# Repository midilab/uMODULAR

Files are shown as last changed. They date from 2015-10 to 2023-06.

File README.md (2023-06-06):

# uMODULAR

A collection of **hardware schematics**, **PCBs**, and **libraries** for **real-time embedded applications** in the field of music and video.
  
Image of umodular-v2 series
  
**Hardware:** Modules effortlessly combine to enhance and extend the capabilities of your device.  
**Firmware:** All the challenging and intricate aspects of real-time and concurrency in music or video applications are encapsulated within a safe and intuitive API via libraries.  

The framework provides multi-architecture support, allowing for seamless compilation across various microcontrollers without the need for manual adjustments or modifications. This ensures a streamlined development process and simplifies the programming and debugging tasks associated with real-time and concurrent operations.  

## Hardware

The physical modules are released under the CC-BY-SA 4.0 license and are available in Kicad format, providing electronic schematics and PCB designs for creating your own audio/video/sensorial device controller or signal processing box.  

## Protocol interfaces

The uMODULAR framework is meticulously designed to ensure seamless interoperability with a wide range of audio and video devices available on the market. Its compatibility extends to various protocols and standards, allowing integration with different devices.  
  
Avaliable Interfaces:  
  
**MIDI**  
OSC: **On roadmap**  
CV/GATE: **On roadmap**  
DMX: **On roadmap**  

## Libraries

The firmware libraries are built for the Arduino platform, with support for PlatformIO, and are compatible with various microcontroller architectures and boards, including classic AVRs and modern ARMs.  
  
**AVRs:** ATmega168, ATmega328, ATmega16u4, ATmega32u4 and ATmega2560.  
**ARMs:** ESP32, SAMD21 and All Teensy ARM microcontrollers.  
  
**Boards:** All AVR Arduino boards, All Teensy AVRs and ARMs, ESP32 based boards and Seedstudio XIAO M0.  
  
#### uCtrl

[uCtrl](https://github.com/midilab/uCtrl) is a comprehensive codebase library for the uMODULAR hardware project. It offers a driver layer for all uMODULAR modules and a user interface layer that simplifies the creation, extension, and sharing of advanced Arduino/PlatformIO applications.  
  
With uCtrl, you can achieve realtime-like functionality within the Arduino/PlatformIO ecosystem by leveraging hardware timer interruptions for precise task management. The library provides a resource-safe access through its API, ensuring efficient and reliable operation.  
  
Choose uCtrl for developing robust, portable, and high-performance musical instruments, sequencers, audio/video controllers, and other related machines on the Arduino/PlatformIO platform.  
  
#### uClock

[uClock](https://github.com/midilab/uClock) is a BPM-based Clock Generator Library provides a way to implement BPM clock tick calls using hardware interruption, ensuring the tightest and most accurate clock signal possible.  

## Applications

Real world applications using the uMODULAR framework:  

#### Aciduino V2

The project features a versatile step sequencer clone of Roland’s TB303/TR808, offering up to 16 tracks. It includes a comprehensive automation grid system for step, pattern, and mute control. The sequencer functions as a MIDI controller and incorporates an OLED display for visual feedback. Furthermore, the design is modular and allows for easy expansion with additional potentiometers, buttons, MIDI, or CV/Gate interfaces.  
  
You can download the app at [aciduino v2 repository](https://github.com/midilab/aciduino/tree/master/v2)  

## Oficial Website

You can find more informations about uMODULAR at http://midilab.co/umodular.

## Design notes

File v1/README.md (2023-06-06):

# V1 release

### Shileds

The initial shield released is compatible with the Arduino Mega, Micro and Mini series boards. However, the project has plans to expand support for other board models in the future.

**\+ Arduino Micro and Mini 5v Compatible** **\+ Arduino Mega Compatible**  
mega_and_mini_shields

### IO Interfaces

The project provides various input and output interfaces, allowing users to interact with the external world effectively.

**\+ FADER8**: 8 x 60mm faders module – designed for Bourns PTA6043-2015DPB103 part. fader8

**\+ POT8**: 8 x potentiometers module – designed for Bourns PTV09A-4015F-B103 part. But it fits for almost all 10KB throughhole potentiometer models.  
pot8

**\+ PUSH8**: 8 x button/led module push8

### Midi Interface

**\+ MIDI4**: Common MIDI interface with support for 2 MIDI Inputs and 2 MIDI Outputs. midi4

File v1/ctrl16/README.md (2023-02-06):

# ctrl16 module

ctrl16 is a 10cmx12.5cm PCB module for uMODULAR platform ready for 16 potentiometers plus 8 buttons/leds to make your device ready for controlling audio or video hardware/software stuffs.

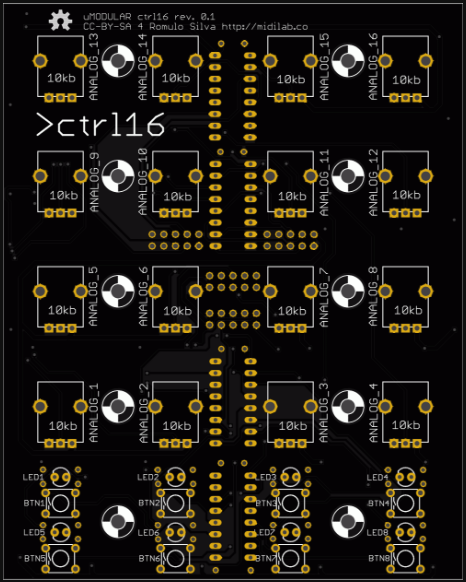
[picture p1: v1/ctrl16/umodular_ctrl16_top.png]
Image of uMODULAR ctrl16 pcb top view

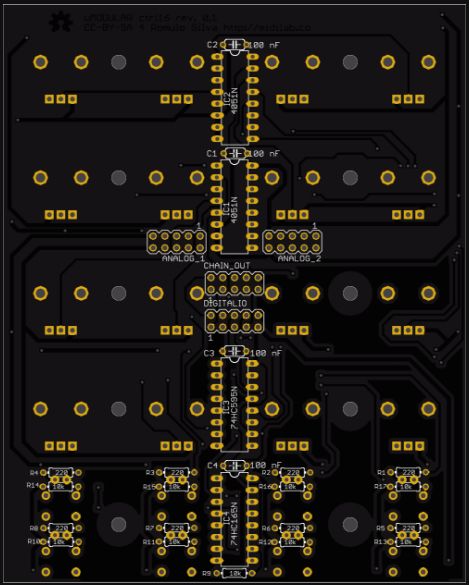
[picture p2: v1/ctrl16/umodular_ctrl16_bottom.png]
Image of uMODULAR ctrl16 pcb bottom view


## BOM list

### Buttons
**8x** Tactile Switches 6.0X4.3MM 160G <br />

### Leds
**8x** Through Hole Diffused T-1 (3 mm) <br />

### Potentiometers
**16x** 10K LINEAR 20%(Bourns PTV09A-4015F-B103) <br />

### ICs
**2x** CD4051BE <br />
**1x** 74HC595N <br />
**1x** 74HC165N <br />
**4x** Socket 16P DUAL WIPE <br />

### Ceramic Disc Capacitors 
**4x** 50V 100nf(.1uF) <br />

### Metal Film Resistors 1/4W Resistors
**8x** 220 <br />
**9x** 10k <br />

### Headers & Wire Housings 
**4x** 05+05 DIL VERTICAL PIN HEADER <br />

### Cable connection for uMODULAR base shield
**pick your size** Ribbon Cable 10 Conductors 28 AWG .050 <br />
**8x** Female Ribbon Cable Header 10 Position, 2 rows, 2.54 mm pitch <br />

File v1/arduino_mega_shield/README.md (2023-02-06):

# uMODULAR Arduino Mega Shield

This is a Arduino Mega Shield to support all uMODULAR modules.

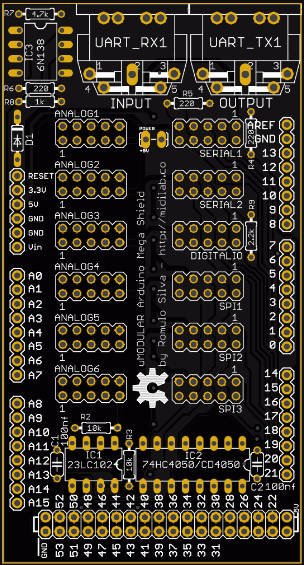
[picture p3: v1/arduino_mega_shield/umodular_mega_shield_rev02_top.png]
Image of uMODULAR Arduino Mega Shield pcb top view

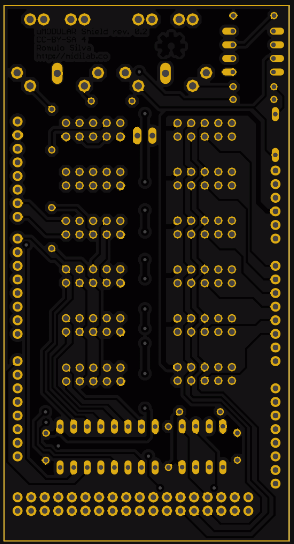
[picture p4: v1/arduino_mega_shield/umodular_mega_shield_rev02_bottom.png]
Image of uMODULAR Arduino Mega Shield pcb bottom view


## BOM list

### ICs
**1x** 23LC1024-I/P <br />
**1x** 74HC4050 <br />
**1x** 6N138 <br />
**1x** Socket 16P DUAL WIPE <br />
**2x** Socket 08P DUAL WIPE <br />

### Ceramic Disc Capacitors
**2x** 50V 100nf(.1uF) <br />

### Metal Film Resistors 1/4W Resistors
**3x** 220 <br />
**1x** 1k <br />
**1x** 2.2k <br />
**1x** 4.7k <br />
**2x** 10k <br />

### Diode
**1x** 1N4148TR <br />

### MIDI Connector
**2x** Circular DIN Connectors 5P R/A PCB SHIELDED 5mm CIRC DIN RECPT <br />

### Headers & Wire Housings
**12x** 05+05 DIL VERTICAL PIN HEADER <br />
**1x** 18+18 DIL VERTICAL PIN HEADER <br />
**5x** 08 SIL VERTICAL PIN HEADER TIN <br />
**1x** 06 SIL VERTICAL PIN HEADER TIN <br />
**1x** 02 SIL VERTICAL PIN HEADER TIN <br />

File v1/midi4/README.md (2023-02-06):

# midi4 module

midi4 is a 10cmx2.5cm PCB module for uMODULAR platform that supports 2 MIDI Ins and 2 MIDI Outs ports.

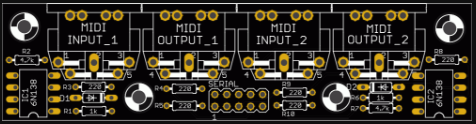
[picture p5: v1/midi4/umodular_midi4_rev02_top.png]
Image of uMODULAR midi4 pcb top view

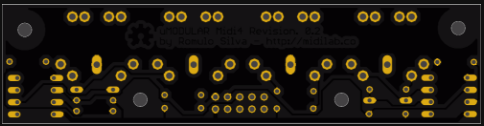
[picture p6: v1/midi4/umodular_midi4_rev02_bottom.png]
Image of uMODULAR midi4 pcb bottom view


## BOM list

### MIDI Connector
**4x** Circular DIN Connectors 5P R/A PCB SHIELDED 5mm CIRC DIN RECPT <br />

### IC
**2x** 6N138 <br />
**2x** Socket 8P DUAL WIPE <br />

### Metal Film Resistors 1/4W Resistors
**2x** 4.7k <br />
**6x** 220 <br />
**2x** 1k <br />

### Diode
**2x** 1N4148 <br />

### Headers & Wire Housings
**1x** 05+05 DIL VERTICAL PIN HEADER <br />

### Cable connection for uMODULAR base shield
**pick your size** Ribbon Cable 10 Conductors 28 AWG .050 <br />
**2x** Female Ribbon Cable Header 10 Position, 2 rows, 2.54 mm pitch <br />

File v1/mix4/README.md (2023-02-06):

# mix4 module

mix4 is a 10cmx12.5cm PCB module for uMODULAR platform ready for 4 faders and 4 potentiometers plus 8 buttons/leds to make your device ready for controlling audio or video hardware/software stuffs.

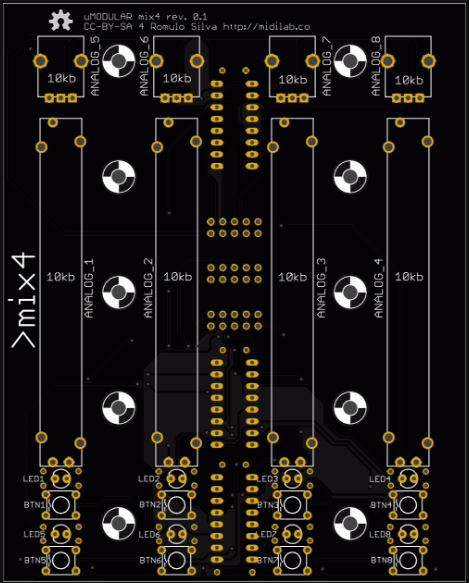
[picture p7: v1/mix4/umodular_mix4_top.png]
Image of uMODULAR mix4 pcb top view

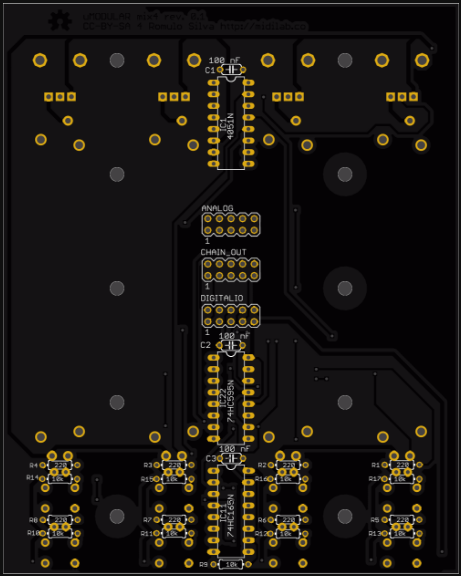
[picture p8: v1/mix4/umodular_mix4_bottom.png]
Image of uMODULAR mix4 pcb bottom view


## BOM list

### Buttons
**8x** Tactile Switches 6.0X4.3MM 160G <br />

### Leds
**8x** Through Hole Diffused T-1 (3 mm) <br />

### Potentiometers
**4x** 10K LINEAR 20% (Bourns PTV09A-4015F-B103) <br />
**4x** Slide 15MM SHAFT NO DET 60MM STRK SNG LIN (Bourns PTA6043-2015DPB103) <br />

### ICs
**1x** CD4051BE <br />
**1x** 74HC595N <br />
**1x** 74HC165N <br />
**3x** Socket 16P DUAL WIPE <br />

### Ceramic Disc Capacitors
**3x** 50V 100nf(.1uF) <br />

### Metal Film Resistors 1/4W Resistors
**8x** 220 <br />
**9x** 10k <br />

### Headers & Wire Housings
**3x** 05+05 DIL VERTICAL PIN HEADER <br />

### Cable connection with uMODULAR base
**pick your size** Ribbon Cable 10 Conductors 28 AWG .050
**6x** Female Ribbon Cable Header 10 Position, 2 rows, 2.54 mm pitch

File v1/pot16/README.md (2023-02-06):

# pot16 module

pot16 is a 10cmx10cm PCB module for uMODULAR platform ready for 16 potentiometers to make your device ready for controlling audio or video hardware/software stuffs.

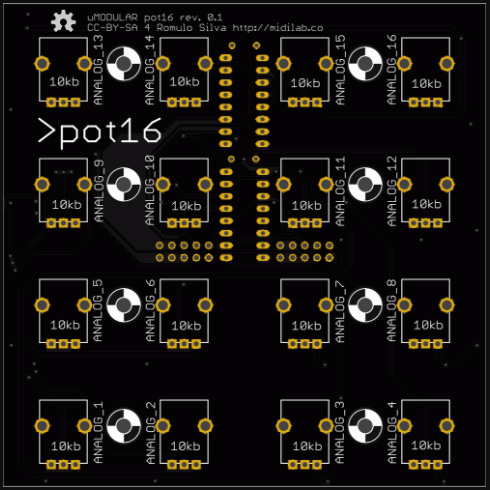
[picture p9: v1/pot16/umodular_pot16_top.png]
Image of uMODULAR pot16 pcb top view

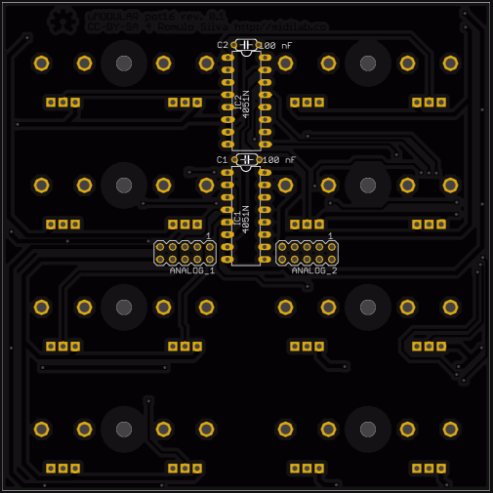
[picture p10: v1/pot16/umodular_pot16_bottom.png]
Image of uMODULAR pot16 pcb bottom view


## BOM list

### Potentiometers
**16x** 10K LINEAR 20%(Bourns PTV09A-4015F-B103) <br />

### ICs
**2x** CD4051BE <br />
**2x** Socket 16P DUAL WIPE <br />

### Ceramic Disc Capacitors
**2x** 50V 100nf(.1uF) <br />

### Headers & Wire Housings
**2x** 05+05 DIL VERTICAL PIN HEADER <br />

### Cable connection with uMODULAR base
**pick your size** Ribbon Cable 10 Conductors 28 AWG .050 <br />
**4x** Female Ribbon Cable Header 10 Position, 2 rows, 2.54 mm pitch <br />

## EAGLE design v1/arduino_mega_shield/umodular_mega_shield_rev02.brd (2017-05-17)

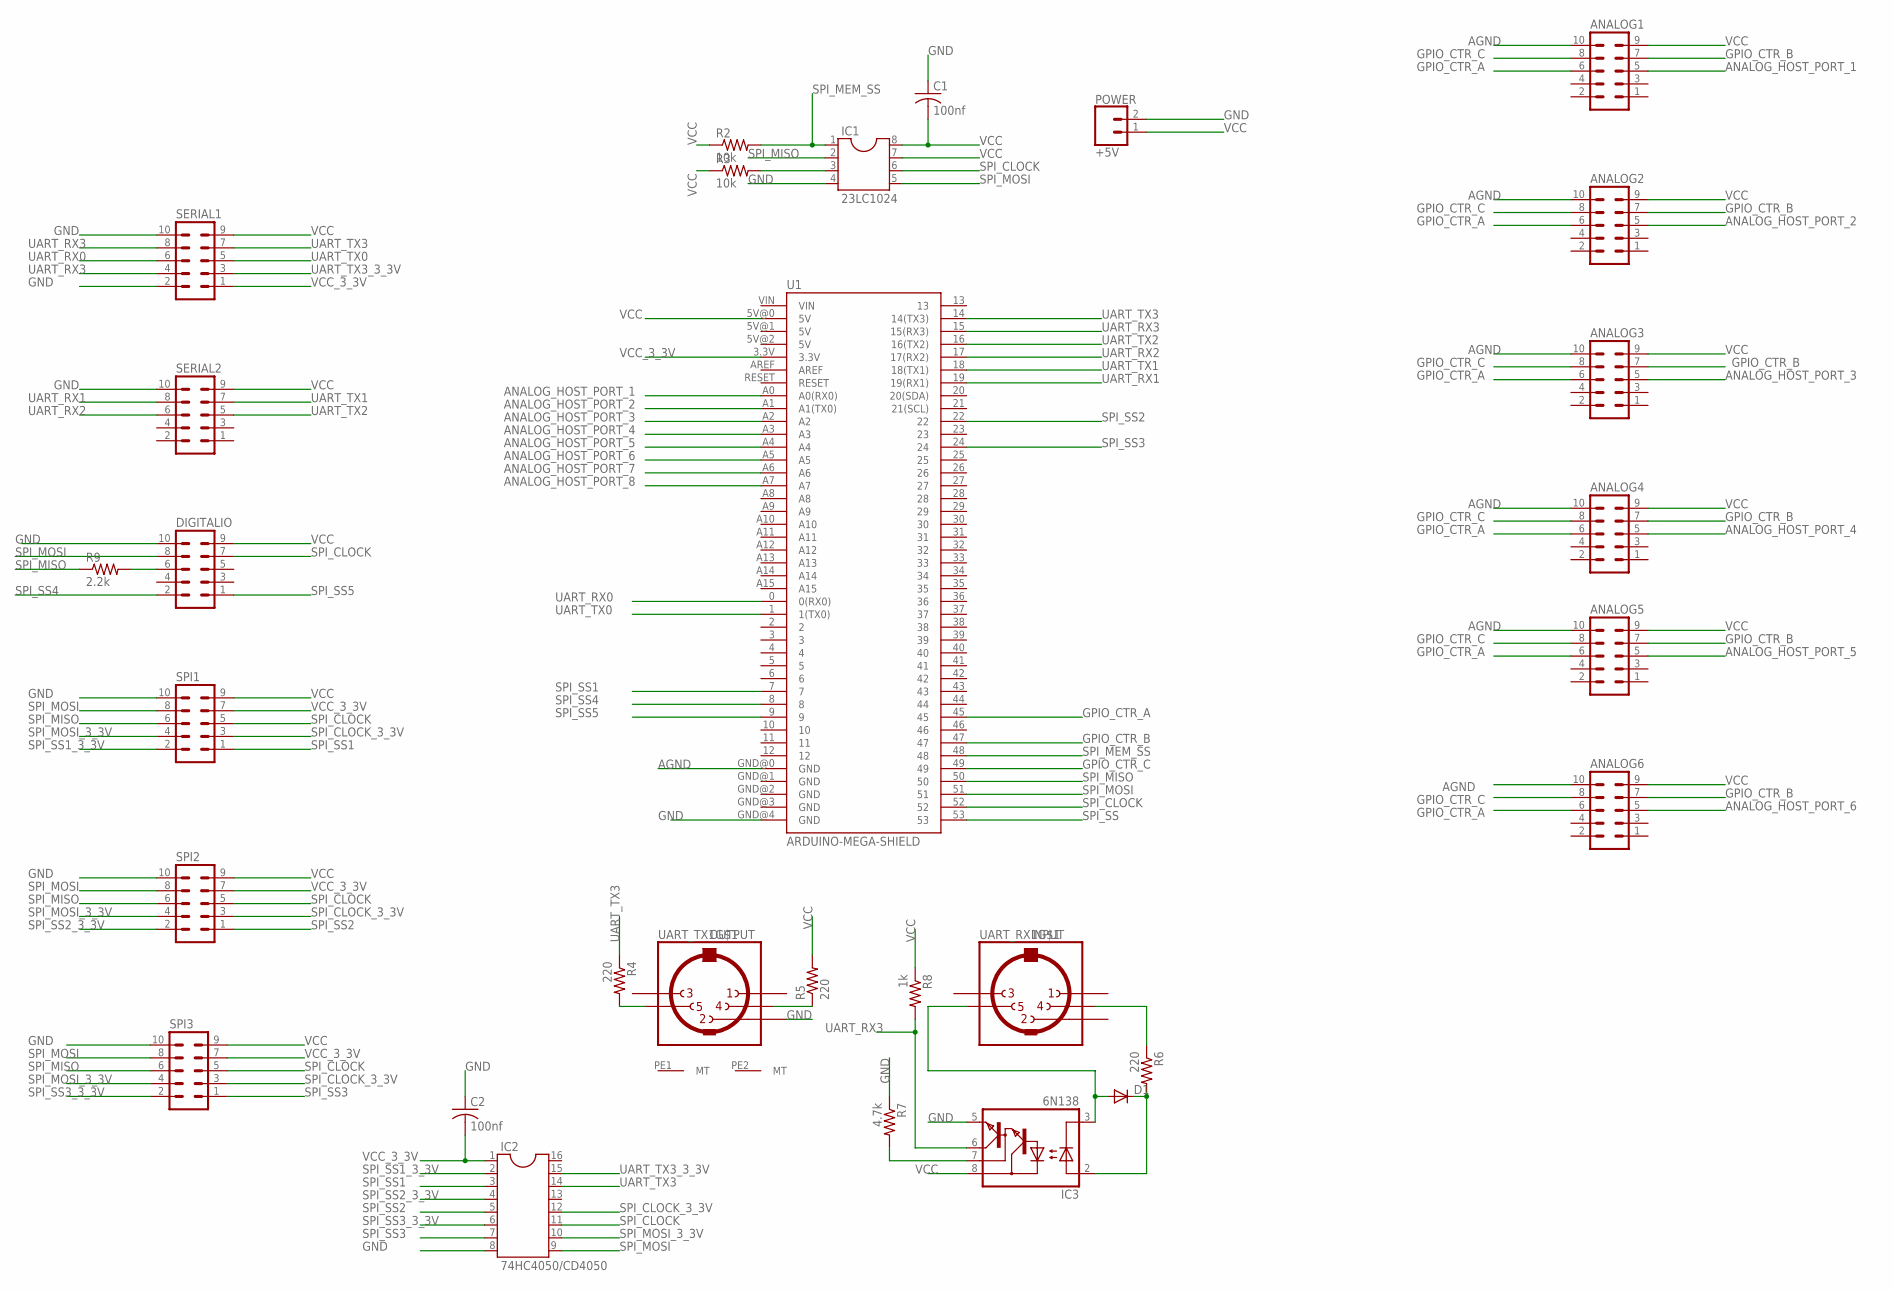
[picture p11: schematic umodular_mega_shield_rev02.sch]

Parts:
ANALOG1, ANALOG2, ANALOG3, ANALOG4, ANALOG5, ANALOG6: MA05-2
C1, C2: 100nf; C050-024X044
D1: 1N4148DO35-7; DO35-7
DIGITALIO: MA05-2
IC1: 23LC1024; DIL08
IC2: 74HC4050/CD4050; DIL16
IC3: 6N138; DIL08
POWER: +5V; 1X02_LOCK_LONGPADS
R2, R3: 10k; 0204/7@1
R4, R5, R6: 220; 0204/7@1
R7: 4.7k; 0204/7@1
R8: 1k; 0204/7@1
R9: 2.2k; 0204/7@1
SERIAL1, SERIAL2: MA05-2
SPI1, SPI2, SPI3: MA05-2
U1: ARDUINO-MEGA-SHIELD; ARDUINO_MEGA@1
UART_RX1: INPUT; CP-2350
UART_TX1: OUTPUT; CP-2350

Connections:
AGND: ANALOG1.10, ANALOG2.10, ANALOG3.10, ANALOG4.10, ANALOG5.10, ANALOG6.10, U1.GND@0 (GND)
ANALOG_HOST_PORT_1: ANALOG1.5, U1.A0 (A0(RX0))
ANALOG_HOST_PORT_2: ANALOG2.5, U1.A1 (A1(TX0))
ANALOG_HOST_PORT_3: ANALOG3.5, U1.A2
ANALOG_HOST_PORT_4: ANALOG4.5, U1.A3
ANALOG_HOST_PORT_5: ANALOG5.5, U1.A4
ANALOG_HOST_PORT_6: ANALOG6.5, U1.A5
ANALOG_HOST_PORT_7: U1.A6
ANALOG_HOST_PORT_8: U1.A7
GND: C1.1, C2.1, DIGITALIO.10, IC1.4, IC2.8, IC3.5 (GND), POWER.2, R7.1, SERIAL1.2, SERIAL1.10, SERIAL2.10, SPI1.10, SPI2.10, SPI3.10, U1.GND@4 (GND), UART_TX1.2
GPIO_CTR_A: ANALOG1.6, ANALOG2.6, ANALOG3.6, ANALOG4.6, ANALOG5.6, ANALOG6.6, U1.45
GPIO_CTR_B: ANALOG1.7, ANALOG2.7, ANALOG3.7, ANALOG4.7, ANALOG5.7, ANALOG6.7, U1.47
GPIO_CTR_C: ANALOG1.8, ANALOG2.8, ANALOG3.8, ANALOG4.8, ANALOG5.8, ANALOG6.8, U1.49
unnamed: R5.1, UART_TX1.4
unnamed: R4.2, UART_TX1.5
unnamed: IC1.3, R3.2
unnamed: R6.1, UART_RX1.4
unnamed: D1.C, IC3.2 (A), R6.2
unnamed: D1.A, IC3.3 (C), UART_RX1.5
unnamed: IC3.7 (VB), R7.2
unnamed: DIGITALIO.6, R9.2
SPI_CLOCK: DIGITALIO.7, IC1.6, IC2.11, SPI1.5, SPI2.5, SPI3.5, U1.52
SPI_CLOCK_3_3V: IC2.12, SPI1.3, SPI2.3, SPI3.3
SPI_MEM_SS: IC1.1, R2.2, U1.48
SPI_MISO: IC1.2, R9.1, SPI1.6, SPI2.6, SPI3.6, U1.50
SPI_MOSI: DIGITALIO.8, IC1.5, IC2.9, SPI1.8, SPI2.8, SPI3.8, U1.51
SPI_MOSI_3_3V: IC2.10, SPI1.4, SPI2.4, SPI3.4
SPI_SS: U1.53
SPI_SS1: IC2.3, SPI1.1, U1.7
SPI_SS1_3_3V: IC2.2, SPI1.2
SPI_SS2: IC2.5, SPI2.1, U1.22
SPI_SS2_3_3V: IC2.4, SPI2.2
SPI_SS3: IC2.7, SPI3.1, U1.24
SPI_SS3_3_3V: IC2.6, SPI3.2
SPI_SS4: DIGITALIO.2, U1.8
SPI_SS5: DIGITALIO.1, U1.9
UART_RX0: SERIAL1.6, U1.0 (0(RX0))
UART_RX1: SERIAL2.8, U1.19 (19(RX1))
UART_RX2: SERIAL2.6, U1.17 (17(RX2))
UART_RX3: IC3.6 (VO), R8.2, SERIAL1.4, SERIAL1.8, U1.15 (15(RX3))
UART_TX0: SERIAL1.5, U1.1 (1(TX0))
UART_TX1: SERIAL2.7, U1.18 (18(TX1))
UART_TX2: SERIAL2.5, U1.16 (16(TX2))
UART_TX3: IC2.14, R4.1, SERIAL1.7, U1.14 (14(TX3))
UART_TX3_3_3V: IC2.15, SERIAL1.3
VCC: ANALOG1.9, ANALOG2.9, ANALOG3.9, ANALOG4.9, ANALOG5.9, ANALOG6.9, C1.2, DIGITALIO.9, IC1.7, IC1.8, IC3.8 (VCC), POWER.1, R2.1, R3.1, R5.2, R8.1, SERIAL1.9, SERIAL2.9, SPI1.9, SPI2.9, SPI3.9, U1.5V@0 (5V)
VCC_3_3V: C2.2, IC2.1, SERIAL1.1, SPI1.7, SPI2.7, SPI3.7, U1.3.3V

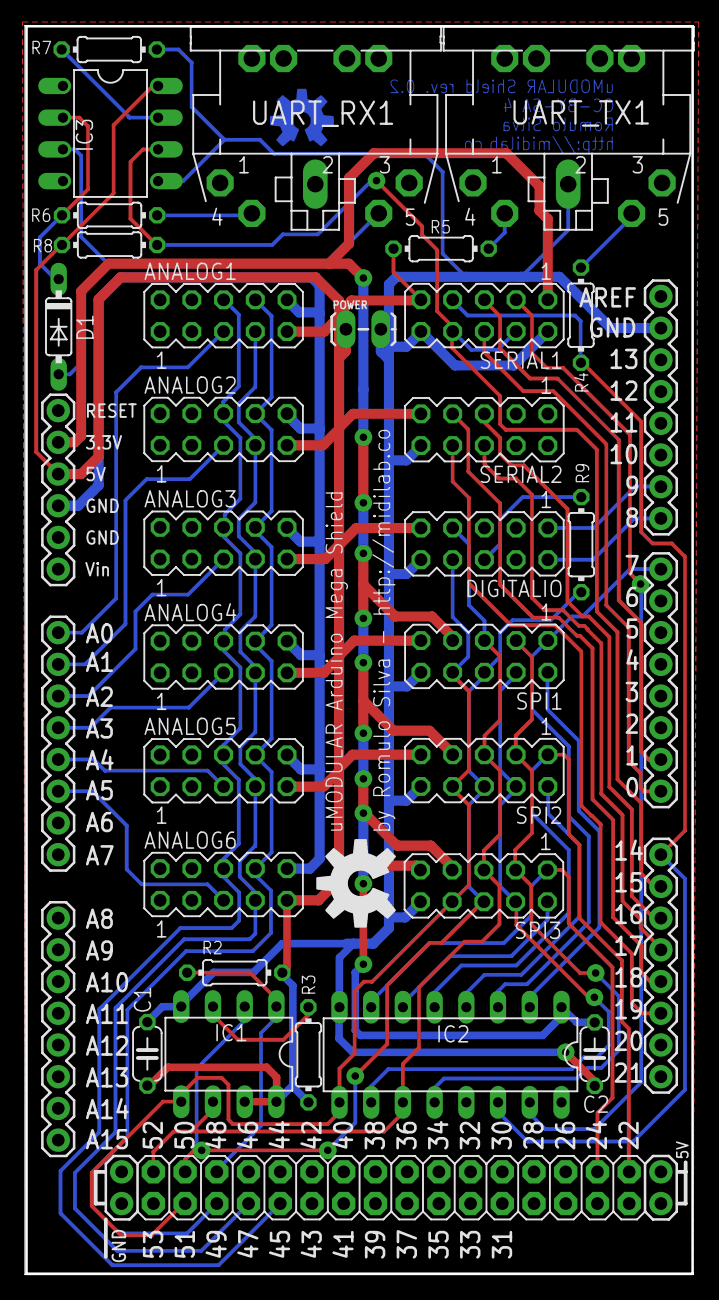
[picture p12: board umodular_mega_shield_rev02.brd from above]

Board: 2 copper layers, 53.5 x 100.0 mm, 32 parts (0 on the bottom side), 44 nets.

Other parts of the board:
U$1: OSHW-LOGO-M
U$5: OSHW-LOGO-L

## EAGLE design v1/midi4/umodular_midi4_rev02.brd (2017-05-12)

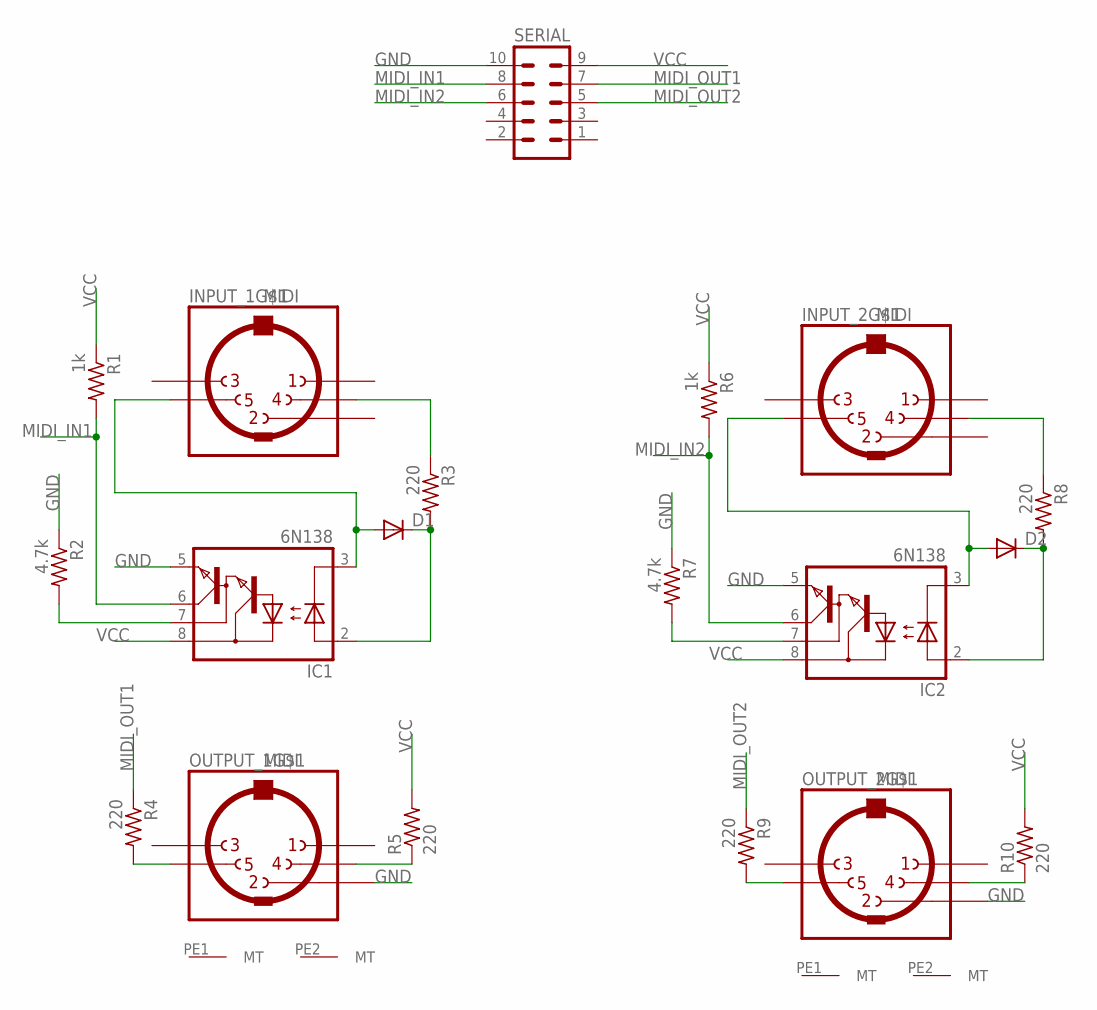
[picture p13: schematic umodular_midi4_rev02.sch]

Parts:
D1, D2: 1N4148DO35-7; DO35-7
IC1, IC2: 6N138; DIL08
INPUT_1, INPUT_2: MIDI; CP-2350
OUTPUT_1, OUTPUT_2: MIDI; CP-2350
R1, R6: 1k; 0204/7@1
R2, R7: 4.7k; 0204/7@1
R3, R4, R5, R8, R9, R10: 220; 0204/7@1
SERIAL: MA05-2

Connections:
GND: IC1.5 (GND), IC2.5 (GND), OUTPUT_1.2, OUTPUT_2.2, R2.1, R7.1, SERIAL.10
MIDI_IN1: IC1.6 (VO), R1.2, SERIAL.8
MIDI_IN2: IC2.6 (VO), R6.2, SERIAL.6
MIDI_OUT1: R4.1, SERIAL.7
MIDI_OUT2: R9.1, SERIAL.5
unnamed: OUTPUT_2.4, R10.1
unnamed: OUTPUT_2.5, R9.2
unnamed: INPUT_2.4, R8.1
unnamed: D2.C, IC2.2 (A), R8.2
unnamed: D2.A, IC2.3 (C), INPUT_2.5
unnamed: IC2.7 (VB), R7.2
unnamed: INPUT_1.4, R3.1
unnamed: OUTPUT_1.4, R5.1
unnamed: OUTPUT_1.5, R4.2
unnamed: D1.C, IC1.2 (A), R3.2
unnamed: D1.A, IC1.3 (C), INPUT_1.5
unnamed: IC1.7 (VB), R2.2
VCC: IC1.8 (VCC), IC2.8 (VCC), R1.1, R5.2, R6.1, R10.2, SERIAL.9

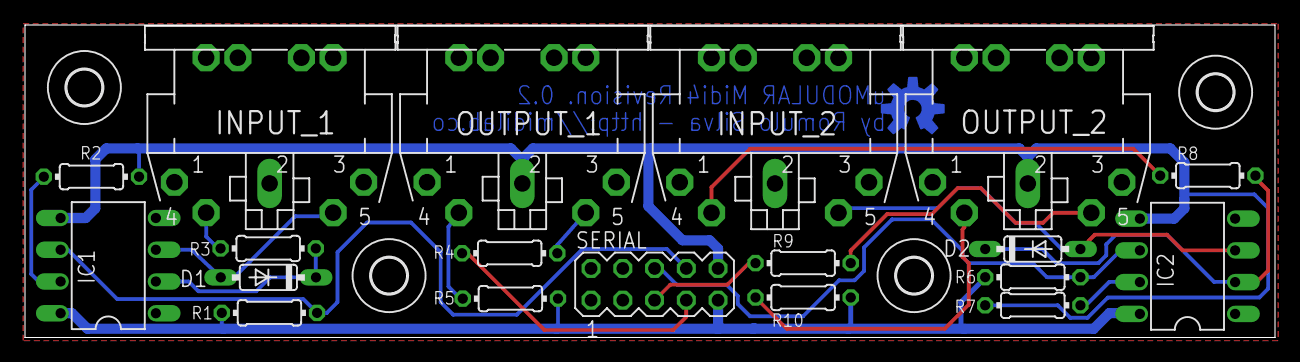
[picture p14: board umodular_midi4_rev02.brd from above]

Board: 2 copper layers, 100.0 x 25.0 mm, 24 parts (0 on the bottom side), 18 nets.

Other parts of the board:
U$1, U$2, U$3, U$4: 2,8
U$6: OSHW-LOGO-M_COPPER

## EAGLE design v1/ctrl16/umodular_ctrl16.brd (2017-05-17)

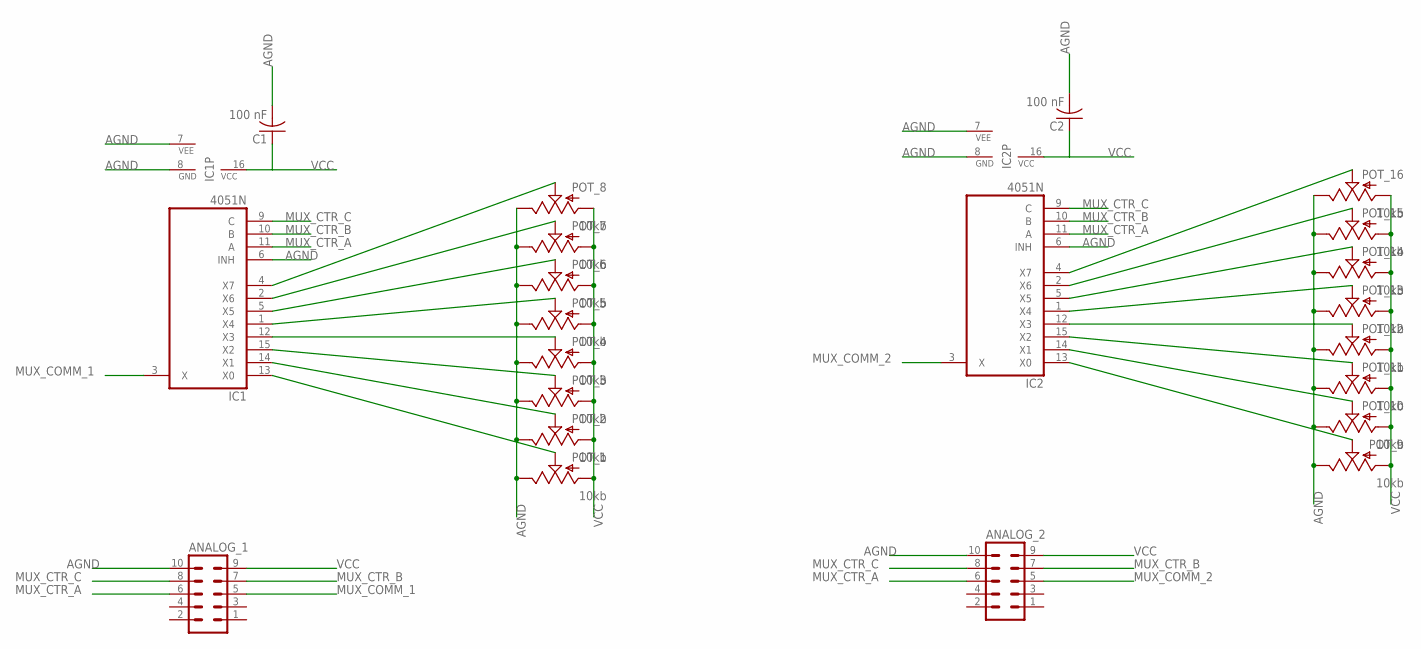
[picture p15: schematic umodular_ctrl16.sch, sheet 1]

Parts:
ANALOG_1, ANALOG_2: MA05-2
C1, C2: 100 nF; C050-024X044
IC1, IC2: 4051N; DIL16
POT_1, POT_2, POT_3, POT_4, POT_5, POT_6, POT_7, POT_8, POT_9, POT_10, POT_11, POT_12, POT_13, POT_14, POT_15, POT_16: 10kb; ALPS_POT

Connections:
AGND: ANALOG_1.10, ANALOG_2.10, C1.2, C2.2, IC1.6 (INH), IC1.7 (VEE), IC1.8 (GND), IC2.6 (INH), IC2.7 (VEE), IC2.8 (GND), POT_1.P$1 (E), POT_2.P$1 (E), POT_3.P$1 (E), POT_4.P$1 (E), POT_5.P$1 (E), POT_6.P$1 (E), POT_7.P$1 (E), POT_8.P$1 (E), POT_9.P$1 (E), POT_10.P$1 (E), POT_11.P$1 (E), POT_12.P$1 (E), POT_13.P$1 (E), POT_14.P$1 (E), POT_15.P$1 (E), POT_16.P$1 (E)
MUX_COMM_1: ANALOG_1.5, IC1.3 (X)
MUX_COMM_2: ANALOG_2.5, IC2.3 (X)
MUX_CTR_A: ANALOG_1.6, ANALOG_2.6, IC1.11 (A), IC2.11 (A)
MUX_CTR_B: ANALOG_1.7, ANALOG_2.7, IC1.10 (B), IC2.10 (B)
MUX_CTR_C: ANALOG_1.8, ANALOG_2.8, IC1.9 (C), IC2.9 (C)
unnamed: IC1.13 (X0), POT_1.P$2 (S)
unnamed: IC1.14 (X1), POT_2.P$2 (S)
unnamed: IC1.15 (X2), POT_3.P$2 (S)
unnamed: IC1.12 (X3), POT_4.P$2 (S)
unnamed: IC1.1 (X4), POT_5.P$2 (S)
unnamed: IC1.5 (X5), POT_6.P$2 (S)
unnamed: IC1.2 (X6), POT_7.P$2 (S)
unnamed: IC1.4 (X7), POT_8.P$2 (S)
unnamed: IC2.13 (X0), POT_9.P$2 (S)
unnamed: IC2.14 (X1), POT_10.P$2 (S)
unnamed: IC2.15 (X2), POT_11.P$2 (S)
unnamed: IC2.12 (X3), POT_12.P$2 (S)
unnamed: IC2.1 (X4), POT_13.P$2 (S)
unnamed: IC2.5 (X5), POT_14.P$2 (S)
unnamed: IC2.2 (X6), POT_15.P$2 (S)
unnamed: IC2.4 (X7), POT_16.P$2 (S)
VCC: ANALOG_1.9, ANALOG_2.9, C1.1, C2.1, IC1.16 (VCC), IC2.16 (VCC), POT_1.P$3 (A), POT_2.P$3 (A), POT_3.P$3 (A), POT_4.P$3 (A), POT_5.P$3 (A), POT_6.P$3 (A), POT_7.P$3 (A), POT_8.P$3 (A), POT_9.P$3 (A), POT_10.P$3 (A), POT_11.P$3 (A), POT_12.P$3 (A), POT_13.P$3 (A), POT_14.P$3 (A), POT_15.P$3 (A), POT_16.P$3 (A); also elsewhere on the board

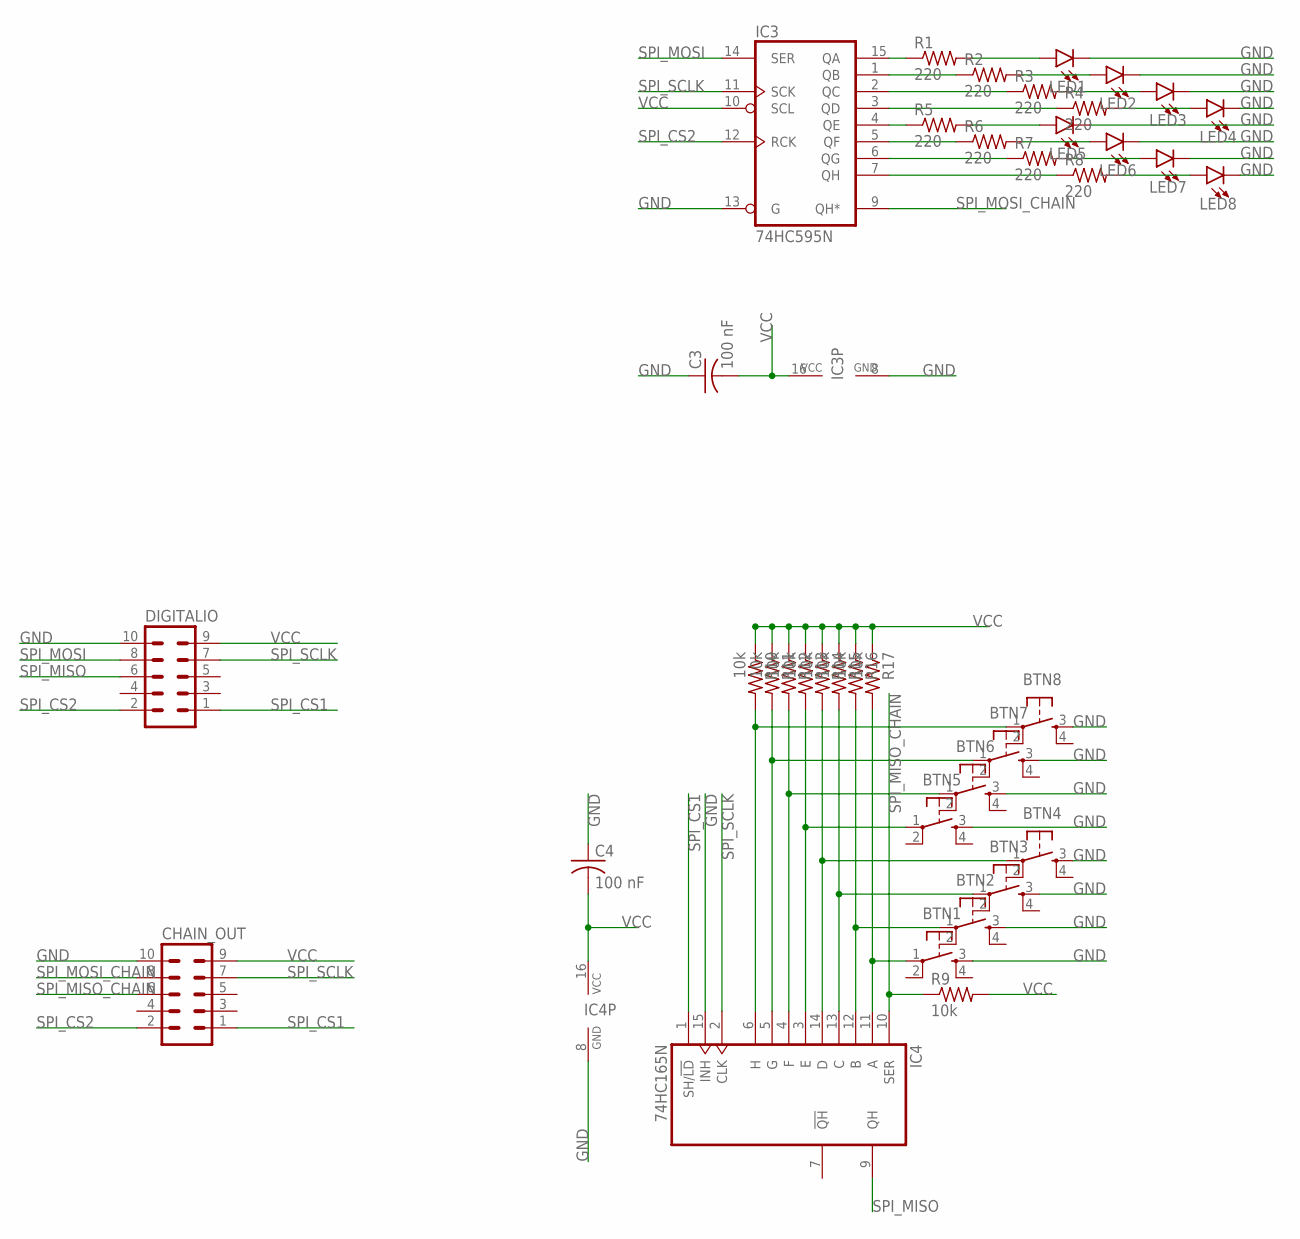
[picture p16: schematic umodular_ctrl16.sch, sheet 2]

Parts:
BTN1, BTN2, BTN3, BTN4, BTN5, BTN6, BTN7, BTN8: TAC_SWITCHPTH; TACTILE-PTH
C3, C4: 100 nF; C050-024X044
CHAIN_OUT: MA05-2
DIGITALIO: MA05-2
IC3: 74HC595N; DIL16
IC4: 74HC165N; DIL16
LED1, LED2, LED3, LED4, LED5, LED6, LED7, LED8: LED3MM; LED_3MM
R1, R2, R3, R4, R5, R6, R7, R8: 220; 0204/7
R9, R10, R11, R12, R13, R14, R15, R16, R17: 10k; 0204/7

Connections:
GND: BTN1.3, BTN2.3, BTN3.3, BTN4.3, BTN5.3, BTN6.3, BTN7.3, BTN8.3, C3.1, C4.1, CHAIN_OUT.10, DIGITALIO.10, IC3.8 (GND), IC3.13 (G), IC4.8 (GND), IC4.15 (INH), LED1.K (C), LED2.K (C), LED3.K (C), LED4.K (C), LED5.K (C), LED6.K (C), LED7.K (C), LED8.K (C)
unnamed: BTN1.1, IC4.11 (A), R17.2
unnamed: BTN2.1, IC4.12 (B), R16.2
unnamed: BTN3.1, IC4.13 (C), R15.2
unnamed: BTN4.1, IC4.14 (D), R14.2
unnamed: BTN5.1, IC4.3 (E), R13.2
unnamed: BTN6.1, IC4.4 (F), R12.2
unnamed: BTN7.1, IC4.5 (G), R11.2
unnamed: BTN8.1, IC4.6 (H), R10.2
unnamed: IC3.7 (QH), R8.1
unnamed: IC3.6 (QG), R7.1
unnamed: IC3.5 (QF), R6.1
unnamed: IC3.4 (QE), R5.1
unnamed: IC3.3 (QD), R4.1
unnamed: IC3.2 (QC), R3.1
unnamed: IC3.1 (QB), R2.1
unnamed: IC3.15 (QA), R1.1
unnamed: LED1.A, R1.2
unnamed: LED2.A, R2.2
unnamed: LED4.A, R4.2
unnamed: LED3.A, R3.2
unnamed: LED5.A, R5.2
unnamed: LED6.A, R6.2
unnamed: LED7.A, R7.2
unnamed: LED8.A, R8.2
SPI_CS1: CHAIN_OUT.1, DIGITALIO.1, IC4.1 (SH/!LD)
SPI_CS2: CHAIN_OUT.2, DIGITALIO.2, IC3.12 (RCK)
SPI_MISO: DIGITALIO.6, IC4.9 (QH)
SPI_MISO_CHAIN: CHAIN_OUT.6, IC4.10 (SER), R9.1
SPI_MOSI: DIGITALIO.8, IC3.14 (SER)
SPI_MOSI_CHAIN: CHAIN_OUT.8, IC3.9 (QH*)
SPI_SCLK: CHAIN_OUT.7, DIGITALIO.7, IC3.11 (SCK), IC4.2 (CLK)
VCC: C3.2, C4.2, CHAIN_OUT.9, DIGITALIO.9, IC3.10 (SCL), IC3.16 (VCC), IC4.16 (VCC), R9.2, R10.1, R11.1, R12.1, R13.1, R14.1, R15.1, R16.1, R17.1; also elsewhere on the board

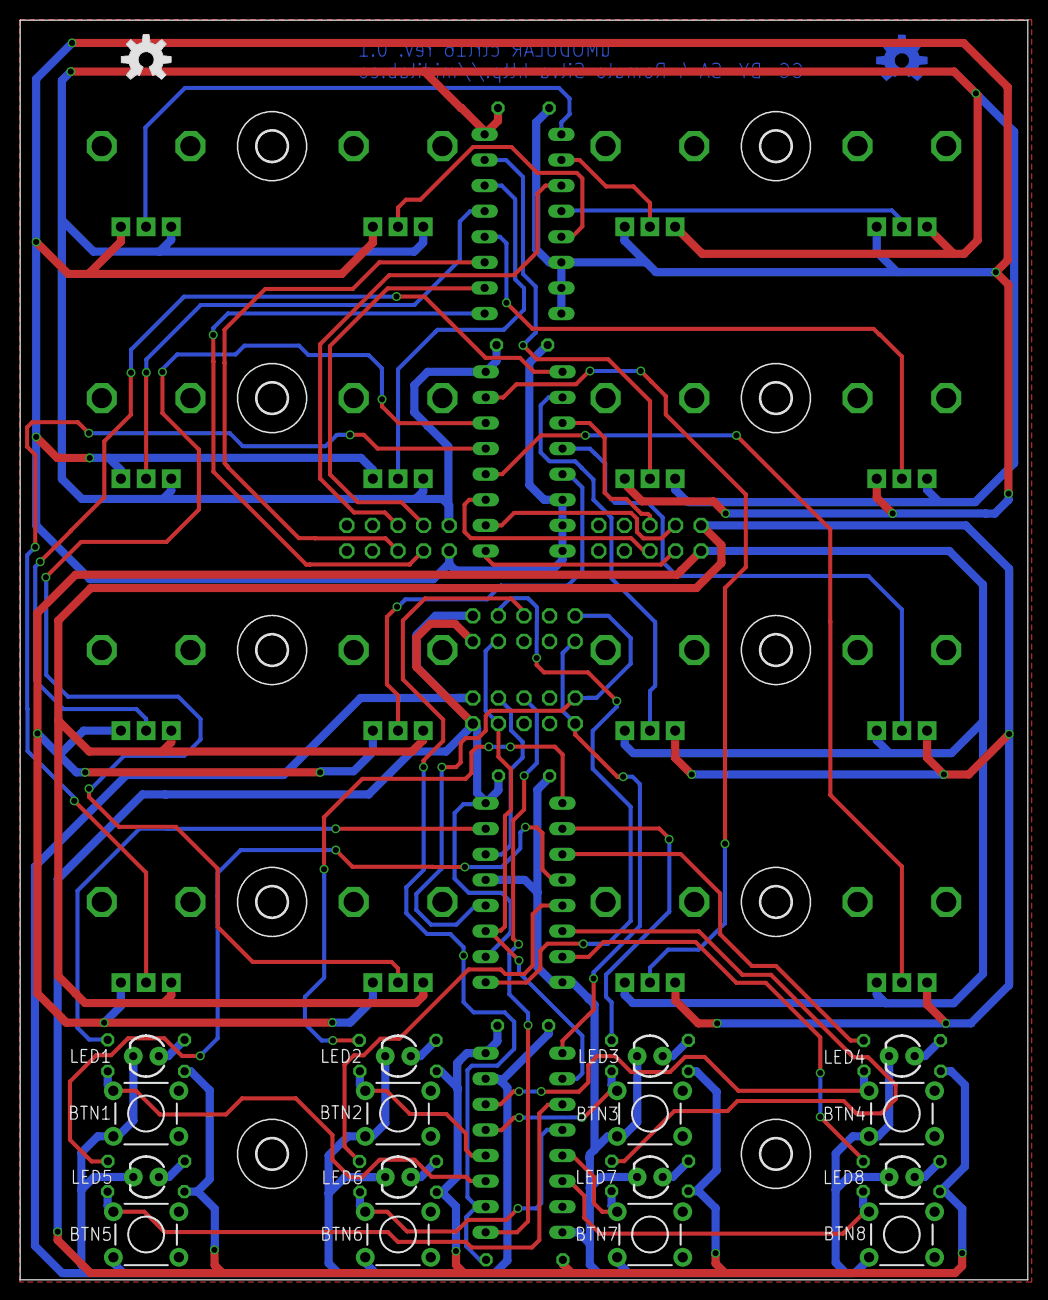
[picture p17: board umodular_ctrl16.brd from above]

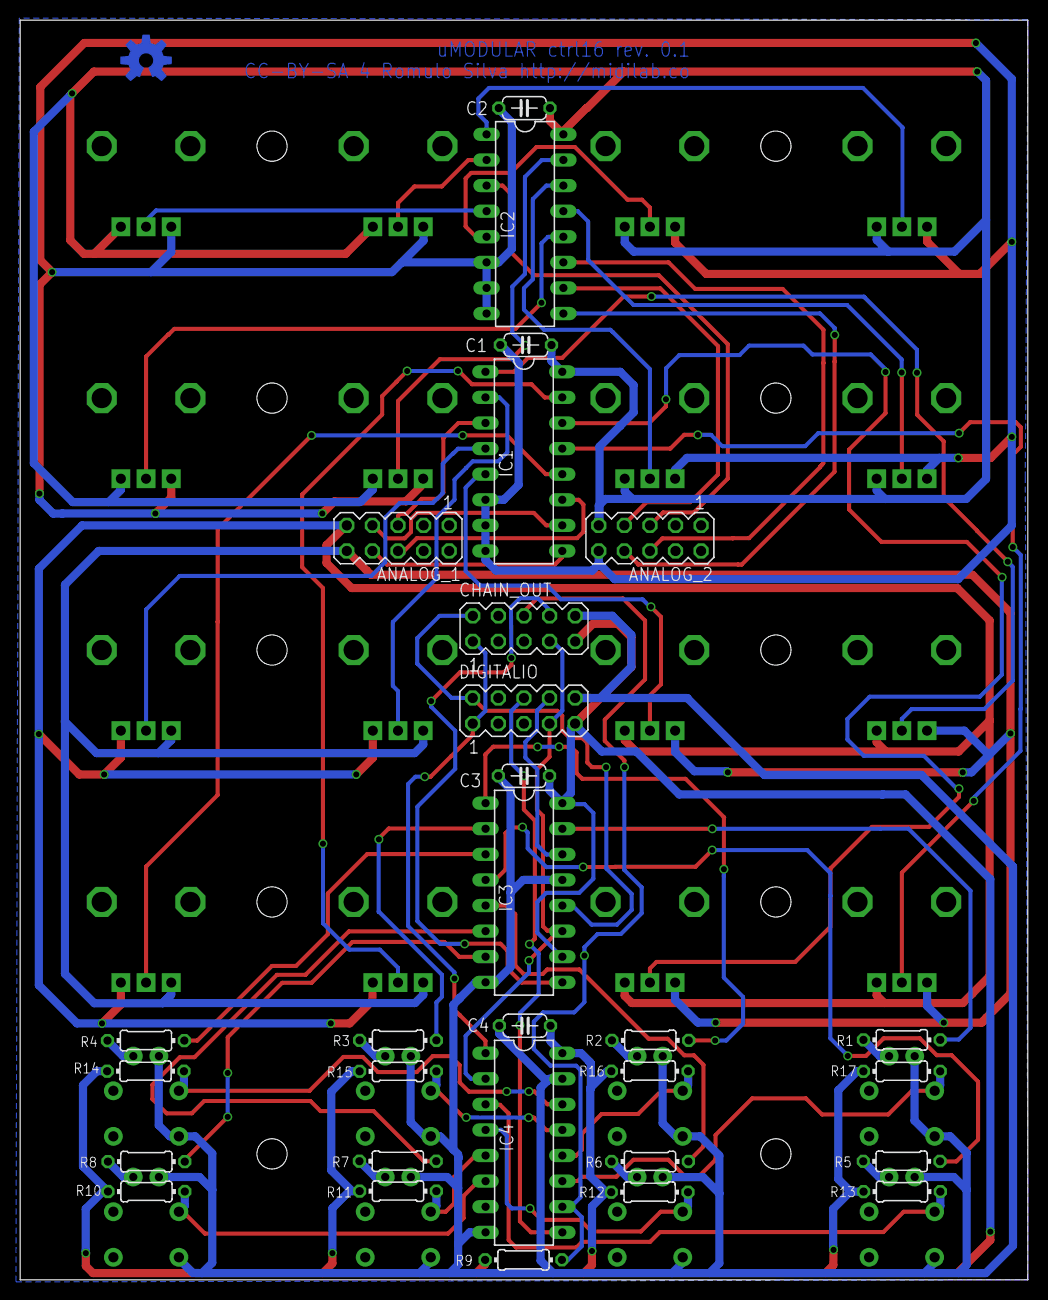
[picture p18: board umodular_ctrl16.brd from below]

Board: 2 copper layers, 100.0 x 125.0 mm, 73 parts (29 on the bottom side), 55 nets.

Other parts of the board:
U$1, U$2, U$3, U$4, U$5, U$6, U$8, U$11, U$12, U$13: 3,0
U$9, U$10: OSHW-LOGO-M

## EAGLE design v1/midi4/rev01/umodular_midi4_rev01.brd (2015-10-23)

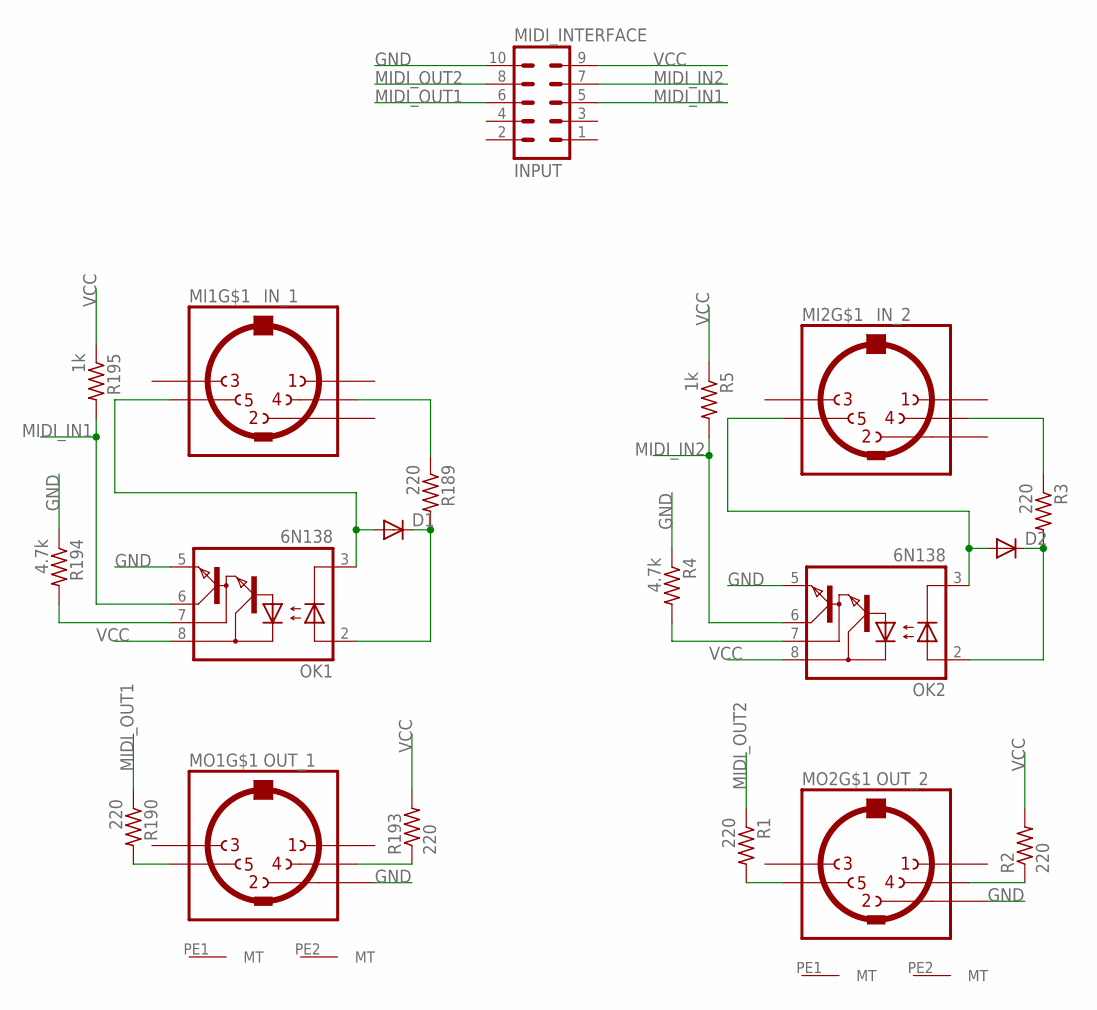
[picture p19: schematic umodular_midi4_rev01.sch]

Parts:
D1, D2: 1N4148DO35-7; DO35-7
MI1: IN_1; CP-2350
MI2: IN_2; CP-2350
MIDI_INTERFACE: INPUT; MA05-2
MO1: OUT_1; CP-2350
MO2: OUT_2; CP-2350
OK1, OK2: 6N138; DIL08
R1, R2, R3, R189, R190, R193: 220; 0204/7@1
R4, R194: 4.7k; 0204/7@1
R5, R195: 1k; 0204/7@1

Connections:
GND: MIDI_INTERFACE.10, MO1.2, MO2.2, OK1.5 (GND), OK2.5 (GND), R4.1, R194.1
MIDI_IN1: MIDI_INTERFACE.5, OK1.6 (VO), R195.2
MIDI_IN2: MIDI_INTERFACE.7, OK2.6 (VO), R5.2
MIDI_OUT1: MIDI_INTERFACE.6, R190.1
MIDI_OUT2: MIDI_INTERFACE.8, R1.1
unnamed: MO2.4, R2.1
unnamed: MO2.5, R1.2
unnamed: MI2.4, R3.1
unnamed: D2.C, OK2.2 (A), R3.2
unnamed: D2.A, MI2.5, OK2.3 (C)
unnamed: OK2.7 (VB), R4.2
unnamed: MI1.4, R189.1
unnamed: MO1.4, R193.1
unnamed: MO1.5, R190.2
unnamed: D1.C, OK1.2 (A), R189.2
unnamed: D1.A, MI1.5, OK1.3 (C)
unnamed: OK1.7 (VB), R194.2
VCC: MIDI_INTERFACE.9, OK1.8 (VCC), OK2.8 (VCC), R2.2, R5.1, R193.2, R195.1

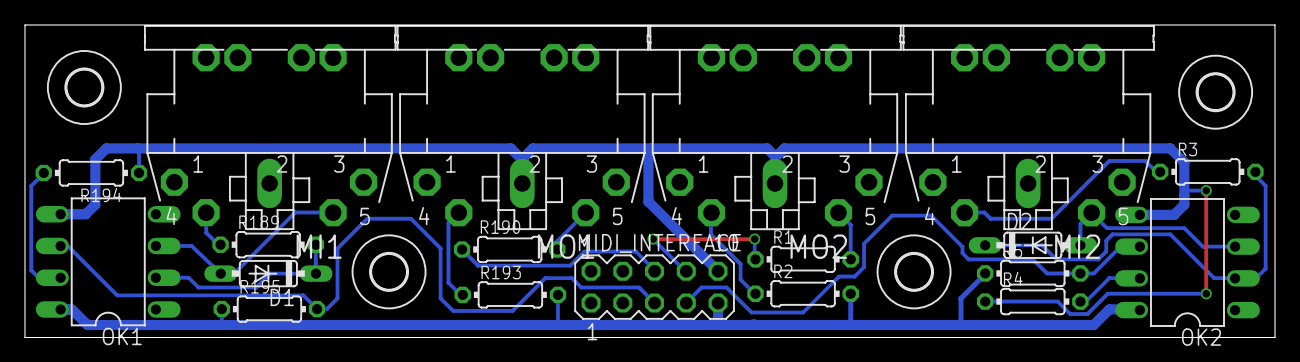
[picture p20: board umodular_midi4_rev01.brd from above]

Board: 2 copper layers, 100.0 x 25.0 mm, 24 parts (0 on the bottom side), 18 nets.

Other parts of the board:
U$1, U$2, U$3, U$4: 2,8
U$5: OSHW-LOGO-M

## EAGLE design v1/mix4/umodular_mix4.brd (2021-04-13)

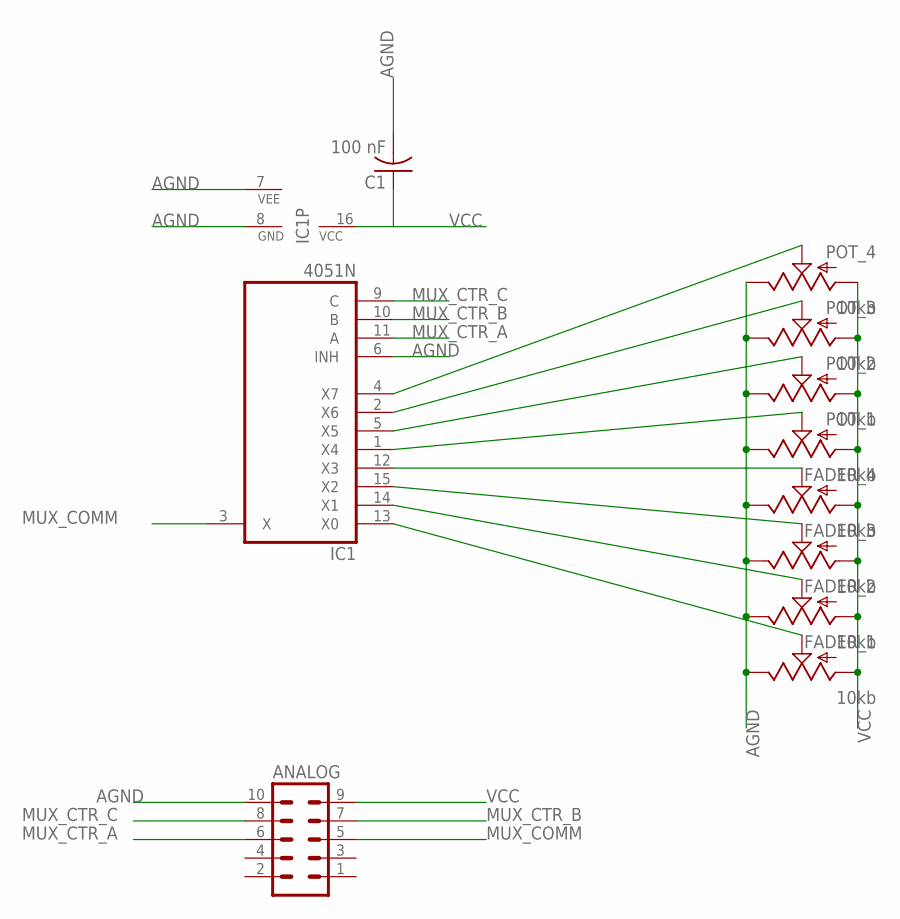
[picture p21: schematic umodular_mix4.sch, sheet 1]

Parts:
ANALOG: MA05-2
C1: 100 nF; C050-024X044
FADER_1, FADER_2, FADER_3, FADER_4: 10kb; SLIDER
IC1: 4051N; DIL16
POT_1, POT_2, POT_3, POT_4: 10kb; ALPS_POT

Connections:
AGND: ANALOG.10, C1.2, FADER_1.1, FADER_2.1, FADER_3.1, FADER_4.1, IC1.6 (INH), IC1.7 (VEE), IC1.8 (GND), POT_1.P$1 (E), POT_2.P$1 (E), POT_3.P$1 (E), POT_4.P$1 (E)
MUX_COMM: ANALOG.5, IC1.3 (X)
MUX_CTR_A: ANALOG.6, IC1.11 (A)
MUX_CTR_B: ANALOG.7, IC1.10 (B)
MUX_CTR_C: ANALOG.8, IC1.9 (C)
unnamed: FADER_1.2, IC1.13 (X0)
unnamed: FADER_2.2, IC1.14 (X1)
unnamed: FADER_3.2, IC1.15 (X2)
unnamed: FADER_4.2, IC1.12 (X3)
unnamed: IC1.1 (X4), POT_1.P$2 (S)
unnamed: IC1.5 (X5), POT_2.P$2 (S)
unnamed: IC1.2 (X6), POT_3.P$2 (S)
unnamed: IC1.4 (X7), POT_4.P$2 (S)
VCC: ANALOG.9, C1.1, FADER_1.3, FADER_2.3, FADER_3.3, FADER_4.3, IC1.16 (VCC), POT_1.P$3 (A), POT_2.P$3 (A), POT_3.P$3 (A), POT_4.P$3 (A); also elsewhere on the board

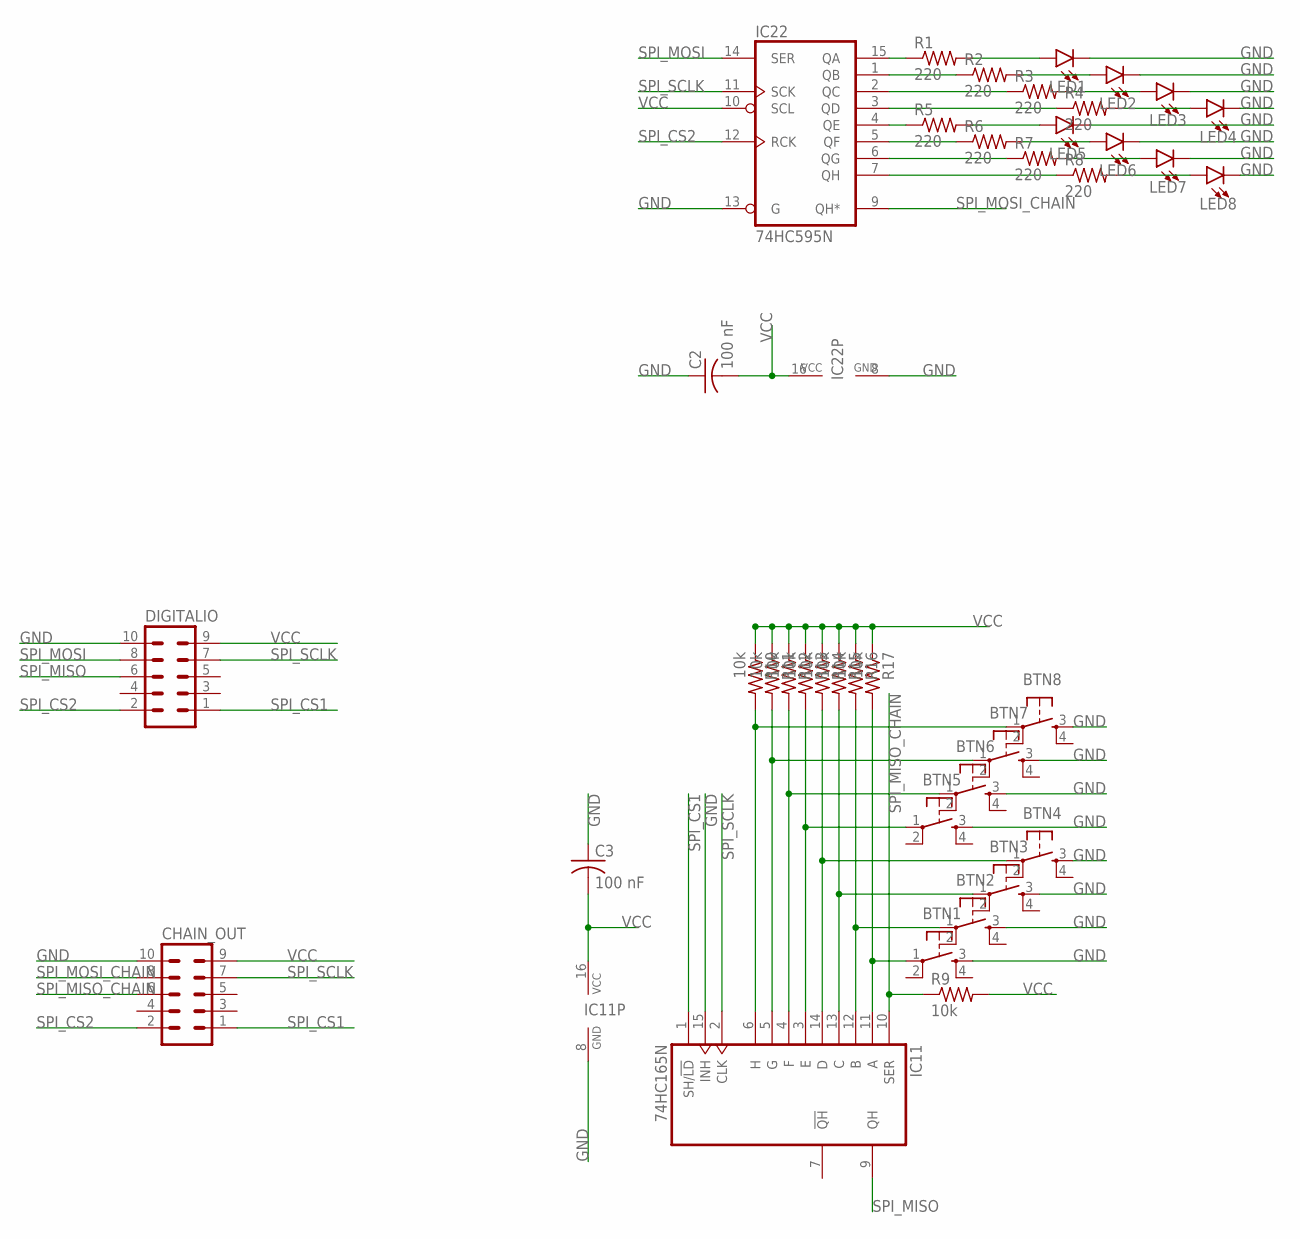
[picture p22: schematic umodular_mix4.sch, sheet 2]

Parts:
BTN1, BTN2, BTN3, BTN4, BTN5, BTN6, BTN7, BTN8: TAC_SWITCHPTH; TACTILE-PTH
C2, C3: 100 nF; C050-024X044
CHAIN_OUT: MA05-2
DIGITALIO: MA05-2
IC11: 74HC165N; DIL16
IC22: 74HC595N; DIL16
LED1, LED2, LED3, LED4, LED5, LED6, LED7, LED8: LED3MM; LED_3MM
R1, R2, R3, R4, R5, R6, R7, R8: 220; 0204/7
R9, R10, R11, R12, R13, R14, R15, R16, R17: 10k; 0204/7

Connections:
GND: BTN1.3, BTN2.3, BTN3.3, BTN4.3, BTN5.3, BTN6.3, BTN7.3, BTN8.3, C2.1, C3.1, CHAIN_OUT.10, DIGITALIO.10, IC11.8 (GND), IC11.15 (INH), IC22.8 (GND), IC22.13 (G), LED1.K (C), LED2.K (C), LED3.K (C), LED4.K (C), LED5.K (C), LED6.K (C), LED7.K (C), LED8.K (C)
unnamed: BTN1.1, IC11.11 (A), R17.2
unnamed: BTN2.1, IC11.12 (B), R16.2
unnamed: BTN3.1, IC11.13 (C), R15.2
unnamed: BTN4.1, IC11.14 (D), R14.2
unnamed: BTN5.1, IC11.3 (E), R13.2
unnamed: BTN6.1, IC11.4 (F), R12.2
unnamed: BTN7.1, IC11.5 (G), R11.2
unnamed: BTN8.1, IC11.6 (H), R10.2
unnamed: IC22.7 (QH), R8.1
unnamed: IC22.6 (QG), R7.1
unnamed: IC22.5 (QF), R6.1
unnamed: IC22.4 (QE), R5.1
unnamed: IC22.3 (QD), R4.1
unnamed: IC22.2 (QC), R3.1
unnamed: IC22.1 (QB), R2.1
unnamed: IC22.15 (QA), R1.1
unnamed: LED1.A, R1.2
unnamed: LED2.A, R2.2
unnamed: LED4.A, R4.2
unnamed: LED3.A, R3.2
unnamed: LED5.A, R5.2
unnamed: LED6.A, R6.2
unnamed: LED7.A, R7.2
unnamed: LED8.A, R8.2
SPI_CS1: CHAIN_OUT.1, DIGITALIO.1, IC11.1 (SH/!LD)
SPI_CS2: CHAIN_OUT.2, DIGITALIO.2, IC22.12 (RCK)
SPI_MISO: DIGITALIO.6, IC11.9 (QH)
SPI_MISO_CHAIN: CHAIN_OUT.6, IC11.10 (SER), R9.1
SPI_MOSI: DIGITALIO.8, IC22.14 (SER)
SPI_MOSI_CHAIN: CHAIN_OUT.8, IC22.9 (QH*)
SPI_SCLK: CHAIN_OUT.7, DIGITALIO.7, IC11.2 (CLK), IC22.11 (SCK)
VCC: C2.2, C3.2, CHAIN_OUT.9, DIGITALIO.9, IC11.16 (VCC), IC22.10 (SCL), IC22.16 (VCC), R9.2, R10.1, R11.1, R12.1, R13.1, R14.1, R15.1, R16.1, R17.1; also elsewhere on the board

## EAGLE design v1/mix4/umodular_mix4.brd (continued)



Board: 2 copper layers, 100.0 x 125.0 mm, 62 parts (26 on the bottom side), 46 nets.

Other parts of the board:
U$1, U$2, U$3, U$4, U$5, U$6, U$8, U$11, U$12, U$13: 3,0
U$9, U$10: OSHW-LOGO-M

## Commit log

2015-10-22 Added arduino Micro and Mini Hardware files rev. 0.1
    [umodular_shiled_amm.brd, umodular_shiled_amm.sch]
2015-10-22 Added notes and visual reference for Arduino micro and mini shiled
2015-10-23 Fader8 Release rev. 0.1
    [umodular_fader8.brd, umodular_fader8.sch]
2015-10-23 Pot8 Release rev. 0.1
    [umodular_pot8.brd, umodular_pot8.sch]
2015-10-23 Midi4 Release rev. 0.1
    [umodular_midi4.brd, umodular_midi4.sch]
2015-12-07 Fix arduino micro/mini shiled size to fixed 10x5cm
    [umodular_shiled_amm.brd]
2015-12-07 Fix module Pot8 size to fixed 10x2.5cm
    [umodular_pot8.brd]
2015-12-07 Fix module Fader8 size to fixed 20x8cm
    [umodular_fader8.brd]
2017-05-12 Subdividing uMODULAR into hardware and libraries repository. Cleaning for new repository strucuture.
    [umodular_fader8.brd, umodular_fader8.sch, umodular_midi4.brd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]
2017-05-12 Adding CC-BY-SA 4 as main License for all hardware schematics and boards
2017-05-12 Adding the Revision 2 of Arduino Shield for Mega.
    [umodular_mega_shield_rev01.brd, umodular_mega_shield_rev01.sch, umodular_mega_shield_rev02.brd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]
2017-05-12 Adding midi4 module Revision 2.
    [umodular_midi4_rev01.brd, umodular_midi4_rev01.sch, umodular_midi4_rev02.brd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]
2017-05-12 Deleting revision 0.1 of umodular shield for arduino mega.
    [umodular_mega_shield_rev01.brd, umodular_mega_shield_rev01.sch]
2017-05-12 Structuring directories
    [umodular_mega_shield_rev02.brd, umodular_mega_shield_rev02.sch, umodular_midi4_rev02.brd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]
2017-05-16 >ctrl16 module working on...
    [umodular_ctrl16.brd, umodular_ctrl16.sch]
2017-05-16 >mix4 module working on...
    [umodular_mix4.brd, umodular_mix4.sch]
2017-05-16 >pot16 module working on...
    [umodular_pot16.brd, umodular_pot16.sch]
2017-05-16 visual reference fix for png board view
2017-05-16 added top view of midi4 module pcb
2017-05-16 added platform arduino mega shiled a external power connector.
    [umodular_mega_shield_rev02.brd, umodular_mega_shield_rev02.sch]
2017-05-17 ctrl16 revision 0.1
    [umodular_ctrl16.brd, umodular_ctrl16.sch]
2017-05-17 mix4 revision 01
    [umodular_mix4.brd, umodular_mix4.sch]
2017-05-17 platform arduino mega shield revision 02
    [umodular_mega_shield_rev02.brd]
2017-05-17 pot16 revision 01
    [umodular_pot16.brd, umodular_pot16.sch]
2017-05-17 updating uMODULAR Arduino Mega Shield project description
2017-05-17 updating ctrl16 BOM list
2017-05-17 updating mix4 BOM list
2017-05-17 updating pot16 BOM list
2017-05-17 updating midi4 BOM list
2017-05-17 updating platform arduino mega shield BOM list
2017-06-14 iface8: working on new module with oled 0.96 support.
    [umodular_iface8_rev01.brd, umodular_iface8_rev01.sch]
2017-06-14 iface8: align components.
    [umodular_iface8_rev01.brd, umodular_iface8_rev01.sch]
2017-06-14 brain8: A 8 bits controlled uMODULAR main brain. Arduino Mega version. Starting Alignment of components
    [umodular_brain8_arduino_mega_rev01.brd, umodular_brain8_arduino_mega_rev01.sch]
2017-06-14 iface8: ready to route boy!
    [umodular_iface8_rev01.brd, umodular_iface8_rev01.sch]
2017-06-14 iface8: final oled adjustment
    [umodular_iface8_rev01.brd]
2017-10-02 Change shift registers from SPI hardware based to Software implementation. Free the SPI bus for things more important(SDCARD and RAM)
    [umodular_mega_shield_rev02.brd, umodular_mega_shield_rev02.sch]
2017-10-12 changes that reflects main hardware connections of project. Hardware SPI are only for RAM memory, sdcard goes via SoftSPI(exclusive wire path) and shift registers 165 and 595 goes via shiftIn and shi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
    [umodular_mega_shield_rev02.brd, umodular_mega_shield_rev02.sch]
2021-04-13 fix bounrs fader part. swaped pin 2 and 1.
    [umodular_mix4.brd, umodular_mix4.sch]
2023-02-03 move old v1 to a archive folder
    [umodular_brain8_arduino_mega_rev01.brd, umodular_brain8_arduino_mega_rev01.sch, umodular_ctrl16.brd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]
2023-02-03 added kicad library for umodular subsystems for reuse on other projects and main repo for maitain and updates
2023-02-03 revert arduino mega shiled back to make use of SPI on shared subsystem
    [umodular_mega_shield_rev02.brd, umodular_mega_shield_rev02.sch]
2023-03-14 added per module pdf schematic

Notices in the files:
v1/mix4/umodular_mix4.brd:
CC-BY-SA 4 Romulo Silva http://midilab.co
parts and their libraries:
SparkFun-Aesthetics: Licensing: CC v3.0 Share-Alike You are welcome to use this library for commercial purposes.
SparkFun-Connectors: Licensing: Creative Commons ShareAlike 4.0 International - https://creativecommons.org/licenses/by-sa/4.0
